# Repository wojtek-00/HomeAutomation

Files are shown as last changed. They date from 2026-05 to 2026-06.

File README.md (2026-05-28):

# HomeAutomation

A modular home automation system built around ESPHome, custom PCB design (KiCad), and 3D-printed enclosures.

The project is designed to be **scalable**, allowing multiple independent hardware modules (controller + expanders) that integrate into a single automation system.

---

# 🧠 System Overview

The project is split into two main domains:

## 🧩 hardware/
Contains all physical devices and their design artifacts:

- PCB designs (KiCad)
- 3D enclosures (STEP / CAD files)
- front panels / UI elements
- production-ready snapshots (releases)

Each hardware module is self-contained.

### Current modules:
- `system_controller` – main brain of the system
- `relay_expander` – relay output module (8 outputs + 8 inputs)
- *(future expanders will be added here)*

---

## ⚙️ system/
Contains software and logic:

- ESPHome configurations
- automation logic (e.g. Home Assistant)
- device behavior definitions
- shared system-level configuration

This layer defines **how devices behave**, not how they are built.

---

# 🏗️ Hardware Module Structure

Each hardware module follows the same structure:
 - hardware/<module_name>/
 - current/ # active development (WIP)
 - releases/ # frozen production versions

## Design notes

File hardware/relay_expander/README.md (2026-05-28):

# Sprinkler Expander Module

## Overview

The **Sprinkler Expander Module** is a modular extension board designed for an ESP32-based controller system used with ESPHome home automation projects.

It provides additional digital I/O capabilities as well as flexible power handling for relay-driven actuator systems.

---

## Features

- 8× relay outputs
- 8× digital inputs
- Modular design for sprinkler and automation systems
- Power distribution system with configurable relay supply
- Designed for integration with ESP32 System Controller

---

## Power Architecture

The module contains two independent power domains:

### 1. Logic Power (5V system supply)

- Onboard **bridge rectifier**
- Used to convert optional **AC input into DC**
- Followed by a **5V buck converter**
- Supplies power for:
  - Relay coils
  - ESP32 System Controller (optional power path)

> This allows the system to be powered either from AC or DC sources.

---

### 2. Relay Power Domain

Relay outputs are powered separately from the logic section.

- Default supply: **24VAC (or equivalent external supply)**
- Each relay bank can be powered from a shared rail

#### Individual relay isolation

Each relay channel can be electrically isolated from the main relay power rail by removing a **jumper**.

This allows:
- independent relay supply per channel
- mixed-voltage operation
- custom actuator voltage per output

---

## System Behavior

- Logic section is always powered via 5V rail
- Relay coils may be powered from:
  - shared 24VAC rail (default mode)
  - or independent external supply per channel (jumper removed)

---

## Application

Typical applications:

- Irrigation / sprinkler control systems
- Valve actuation systems
- Distributed relay automation
- Mixed-voltage industrial control logic

---

## Integration

Designed for use with:

- ESP32 System Controller (ESPHome firmware)
- Modular expansion architecture
- DIN rail mounted enclosures

---

## Notes

- Ensure correct jumper configuration before applying relay power
- Do not mix AC and DC relay supply on the same channel
- Verify coil voltage compatibility before deployment

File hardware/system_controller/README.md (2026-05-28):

# ESP32 Modular DIN Rail Controller for ESPHome

This repository contains PCB schematics and PCB design files for a modular ESP32-based controller designed for use with ESPHome.

The controller supports expansion modules that provide additional functionality such as extra GPIO, PWM outputs, relays, and other peripherals.

---

## Features

- ESP32-based controller
- Designed for ESPHome
- Modular expansion system
- DIN rail mount enclosure
- Easy integration with custom modules

---

## Supported Expansion Modules

Examples of supported modules:

- GPIO expanders
- PWM output modules
- Relay modules
- Analog input modules
- Custom extension boards

---

## Enclosure Parameters (Fusion 360)

| Parameter | Value |
|---|---|
| Enclosure type | `RailEnclosure_One_Side` |
| Board width | `45 mm` |

---

## Project Structure

```text
/pcb            -> PCB design files
/schematics     -> Electrical schematics
/fusion360      -> Enclosure and mechanical design
/docs           -> Documentation
```

---

## Software

The controller is designed to work with ESPHome firmware.

ESPHome allows easy integration with Home Assistant and other home automation systems.

More information:
https://esphome.io/

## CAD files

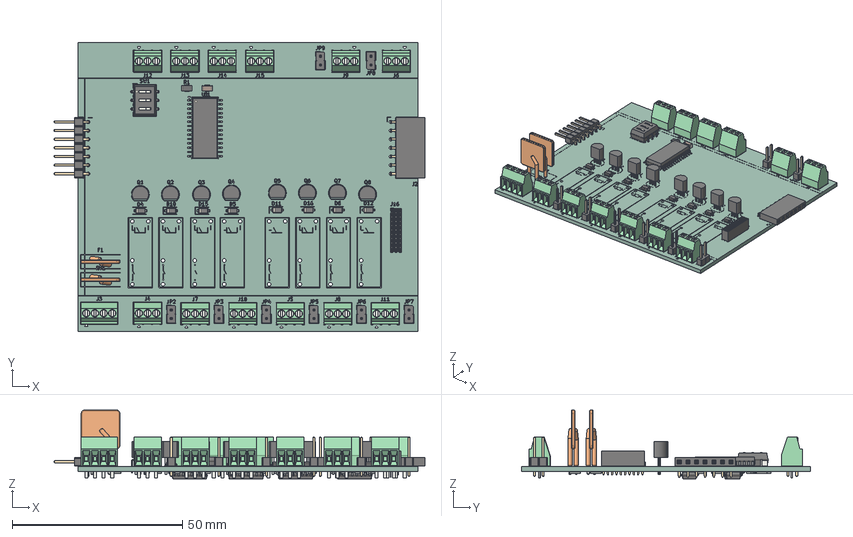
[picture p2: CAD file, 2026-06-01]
hardware/relay_expander/current/pcb/main_board/main_board.step
109.1 x 85.0 x 20.3 mm
R_1206_3216Metric x 44
TerminalBlock_Phoenix_MPT-0,5-4-2.54_1x04_P2.54mm_Horizontal
TerminalBlock_Phoenix_MPT-0,5-3-2.54_1x03_P2.54mm_Horizontal x 12
D_SOD-123 x 8
TO-92_Inline_Narrow x 8
PinHeader_1x02_P254mm_Vertical x 8
SW_DIP_SPSTx03_Slide_67x918mm_W762mm_P254mm_LowProfile
PinHeader_1x07_P254mm_Horizontal
C_1206_3216Metric
PinSocket_2x10_P1.27mm_Vertical
SOIC-28W_7.5x17.9mm_P1.27mm
PinSocket_1x07_P2.54mm_Horizontal
A_0ZRE0033FF x 2
SOP-16_4.4x10.4mm_P1.27mm x 4
main_board_silkscreen x 2
main_board_PCB

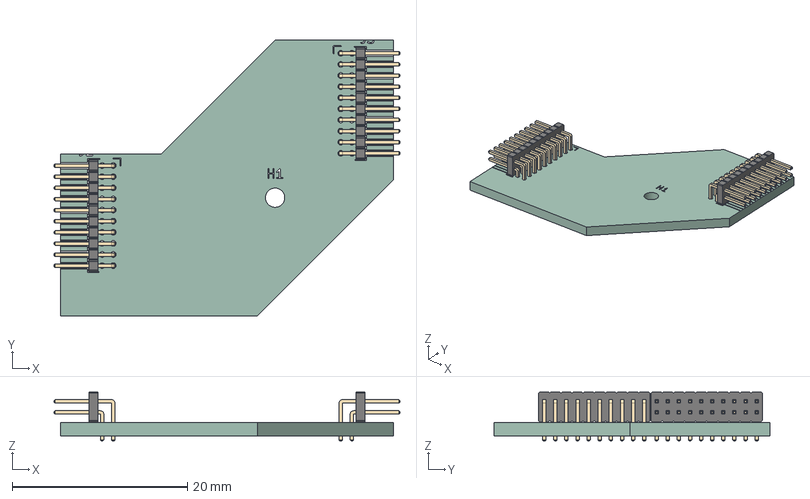
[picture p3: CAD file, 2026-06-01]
hardware/relay_expander/current/pcb/boards_connector/boards_connector.step
39.5 x 31.5 x 5.58 mm
PinHeader_2x10_P127mm_Horizontal x 2
boards_connector_silkscreen
boards_connector_PCB

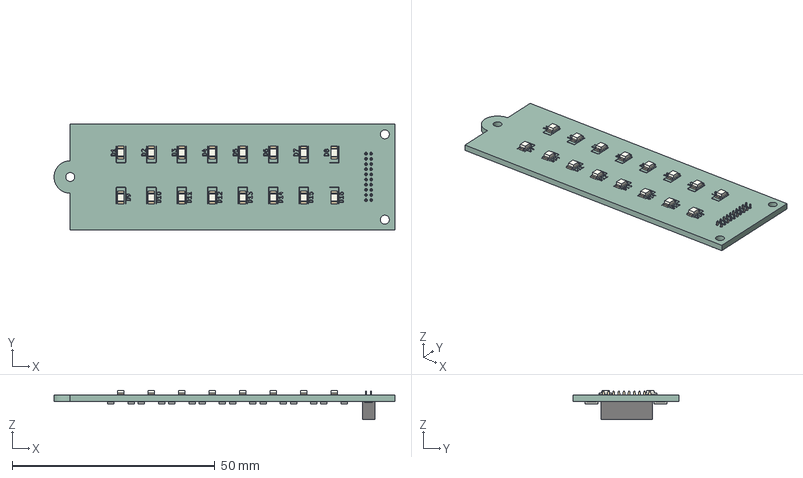
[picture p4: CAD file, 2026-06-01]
hardware/relay_expander/current/pcb/ui_board/ui_board.step
84.0 x 26.0 x 7.18 mm
LED_1206_3216Metric x 16
R_1206_3216Metric x 16
PinSocket_2x10_P1.27mm_Vertical
ui_board_silkscreen x 2
ui_board_PCB

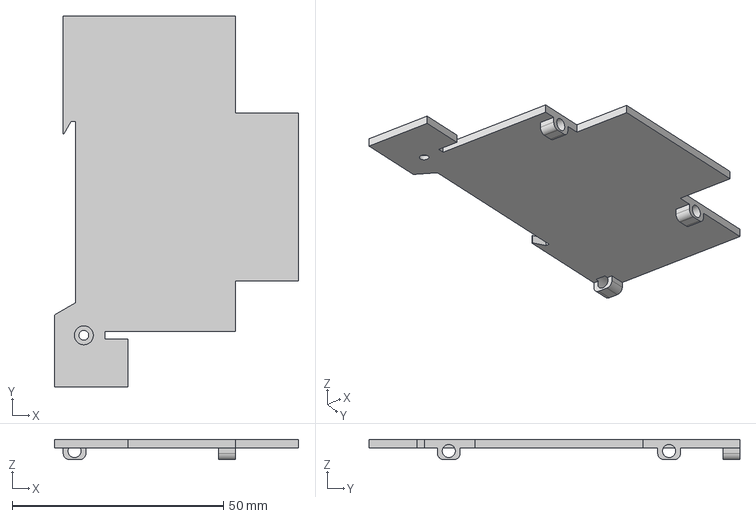
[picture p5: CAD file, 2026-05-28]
hardware/system_controller/current/enclosure/side_lid.step
57.9 x 87.9 x 4.80 mm

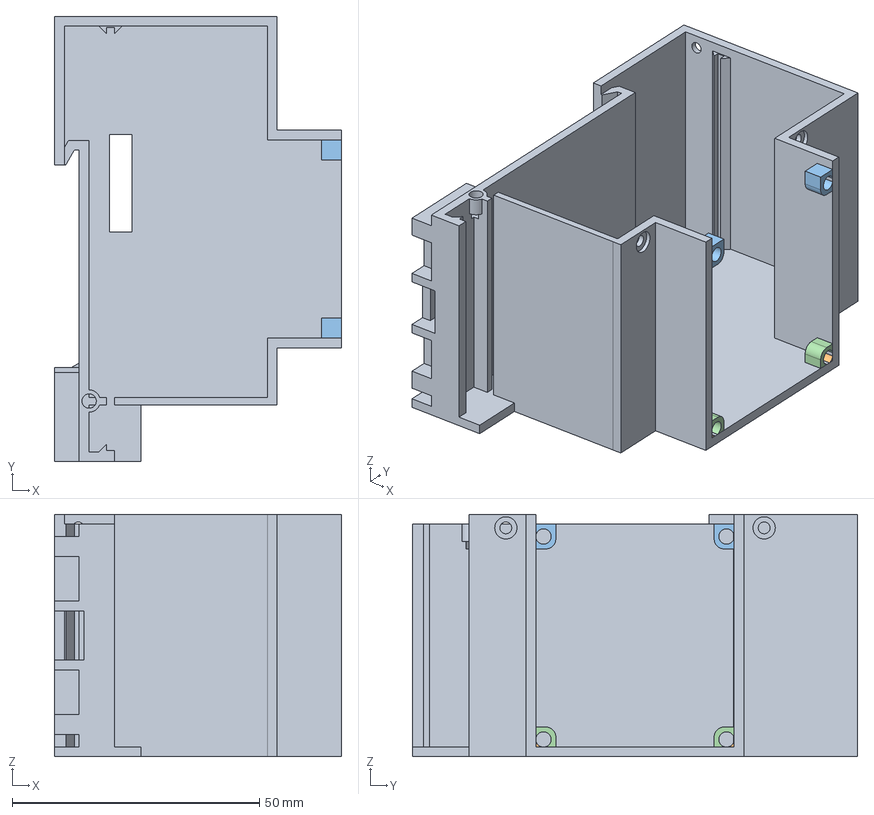
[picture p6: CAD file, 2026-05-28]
hardware/system_controller/current/enclosure/enclosure_base.step
58.0 x 90.0 x 49.0 mm

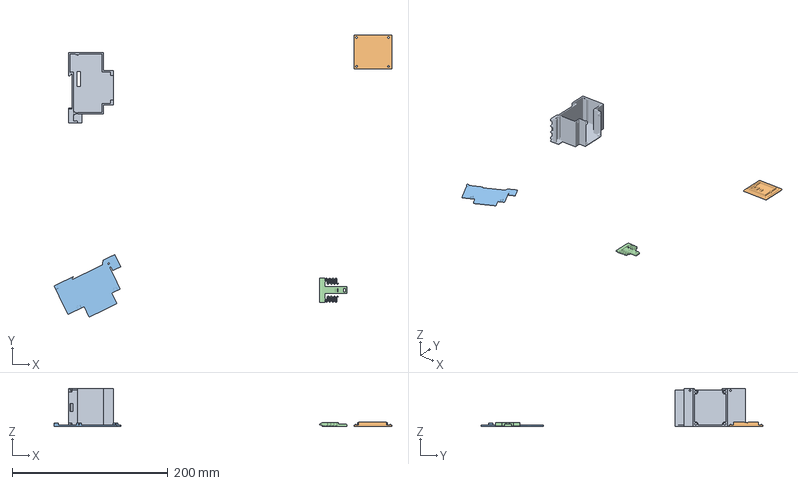
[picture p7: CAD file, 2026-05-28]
hardware/system_controller/releases/v1.0.0/enclosure/print_setup.3mf
433.9 x 362.5 x 49.0 mm
System_Controller_Enclosure.step
LED_Lid_System_Controller.step
Lid_One_Side.step
DIN_2Mod_Clip.STL

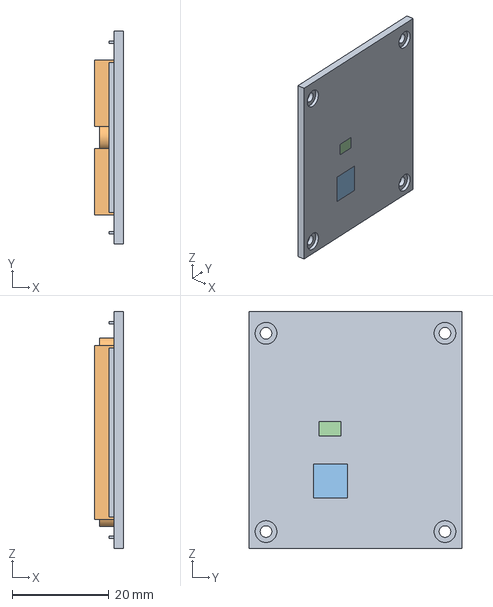
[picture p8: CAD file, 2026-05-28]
hardware/system_controller/current/enclosure/front_panel.step
6.00 x 44.0 x 49.0 mm

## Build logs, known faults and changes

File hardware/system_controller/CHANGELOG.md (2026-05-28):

# System Controller Changelog

## [v1.0.0] - 2026-05-27

### Hardware
- controller_board v1 (ESP32 + power section)
- ui_board v1 (LED + reset + buttons)
- enclosure v1 (3D printed housing)

### Notes
- first working full assembly
- UI LEDs confirmed working

### Release
- stored in hardware/system_controller/releases/v1.0.0

---

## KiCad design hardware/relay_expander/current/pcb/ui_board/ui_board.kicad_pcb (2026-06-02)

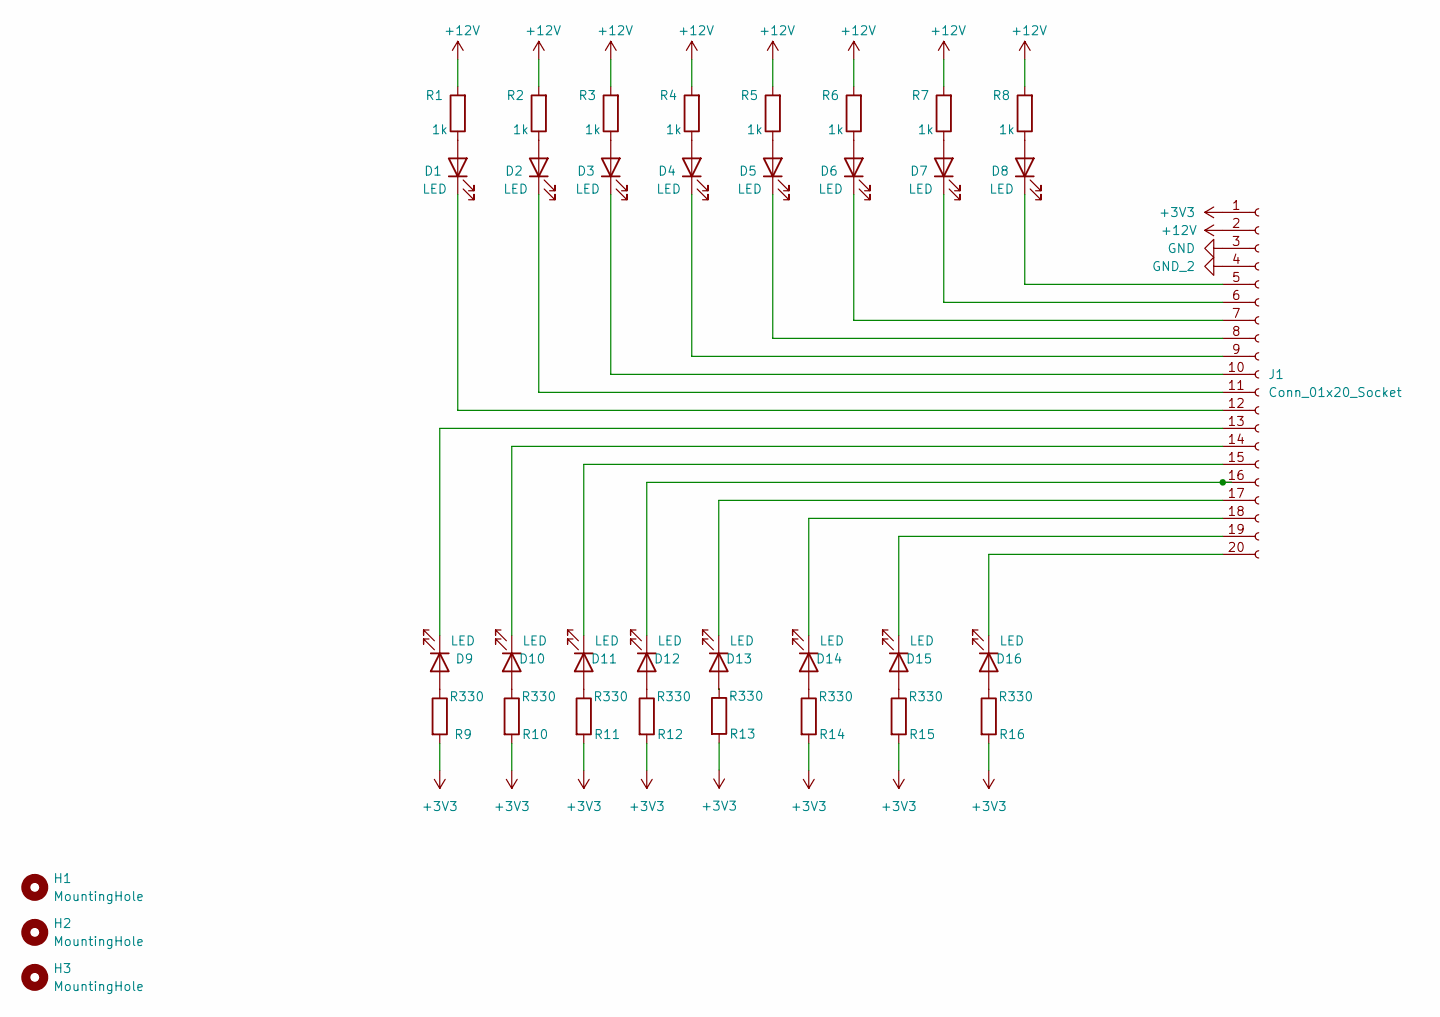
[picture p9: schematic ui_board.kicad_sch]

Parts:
D1, D2, D3, D4, D5, D6, D7, D8, D9, D10, D11, D12, D13, D14, D15, D16: LED; LED_1206_3216Metric_Pad1.42x1.75mm_HandSolder
H1, H2, H3: MountingHole; MountingHole_2.2mm_M2_ISO7380_Pad_TopOnly
J1: Conn_01x20_Socket; PinSocket_2x10_P1.27mm_Vertical
R1, R2, R3, R4, R5, R6, R7, R8: 1k; R_1206_3216Metric_Pad1.30x1.75mm_HandSolder
R9, R10, R11, R12, R13, R14, R15, R16: R330; R_1206_3216Metric_Pad1.30x1.75mm_HandSolder

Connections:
+3V3: J1.1, R9.2, R10.2, R11.2, R12.2, R13.2, R14.2, R15.2, R16.2
+12V: J1.2, R1.2, R2.2, R3.2, R4.2, R5.2, R6.2, R7.2, R8.2
GND: J1.3
GND_2: J1.4
unnamed: D1.2 (A), R1.1
unnamed: D1.1 (K), J1.12
unnamed: D2.2 (A), R2.1
unnamed: D2.1 (K), J1.11
unnamed: D3.2 (A), R3.1
unnamed: D3.1 (K), J1.10
unnamed: D4.2 (A), R4.1
unnamed: D4.1 (K), J1.9
unnamed: D5.2 (A), R5.1
unnamed: D5.1 (K), J1.8
unnamed: D6.2 (A), R6.1
unnamed: D6.1 (K), J1.7
unnamed: D7.2 (A), R7.1
unnamed: D7.1 (K), J1.6
unnamed: D8.2 (A), R8.1
unnamed: D8.1 (K), J1.5
unnamed: D9.2 (A), R9.1
unnamed: D9.1 (K), J1.13
unnamed: D10.2 (A), R10.1
unnamed: D10.1 (K), J1.14
unnamed: D11.2 (A), R11.1
unnamed: D11.1 (K), J1.15
unnamed: D12.2 (A), R12.1
unnamed: D12.1 (K), J1.16
unnamed: D13.2 (A), R13.1
unnamed: D13.1 (K), J1.17
unnamed: D14.2 (A), R14.1
unnamed: D14.1 (K), J1.18
unnamed: D15.2 (A), R15.1
unnamed: D15.1 (K), J1.19
unnamed: D16.2 (A), R16.1
unnamed: D16.1 (K), J1.20

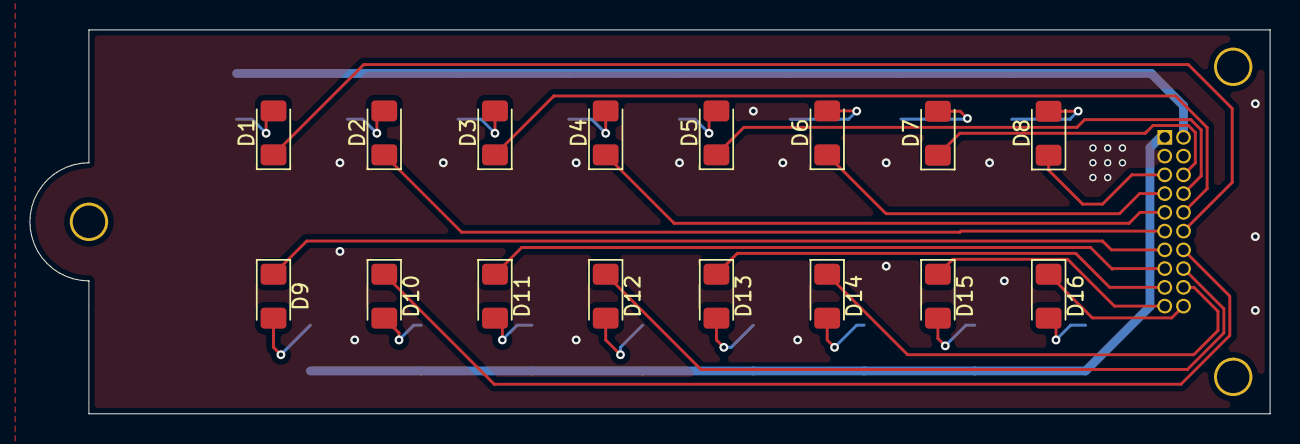
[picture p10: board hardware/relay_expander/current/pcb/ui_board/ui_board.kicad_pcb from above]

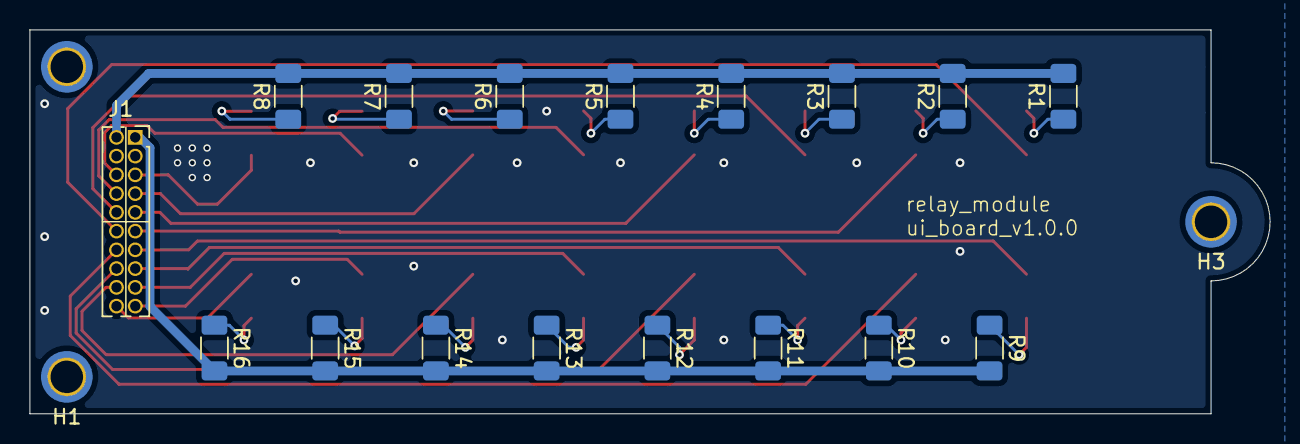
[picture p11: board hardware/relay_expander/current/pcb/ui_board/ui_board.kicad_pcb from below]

Board: 2 copper layers, 84.0 x 26.0 mm, 36 parts (20 on the bottom side), 34 nets.

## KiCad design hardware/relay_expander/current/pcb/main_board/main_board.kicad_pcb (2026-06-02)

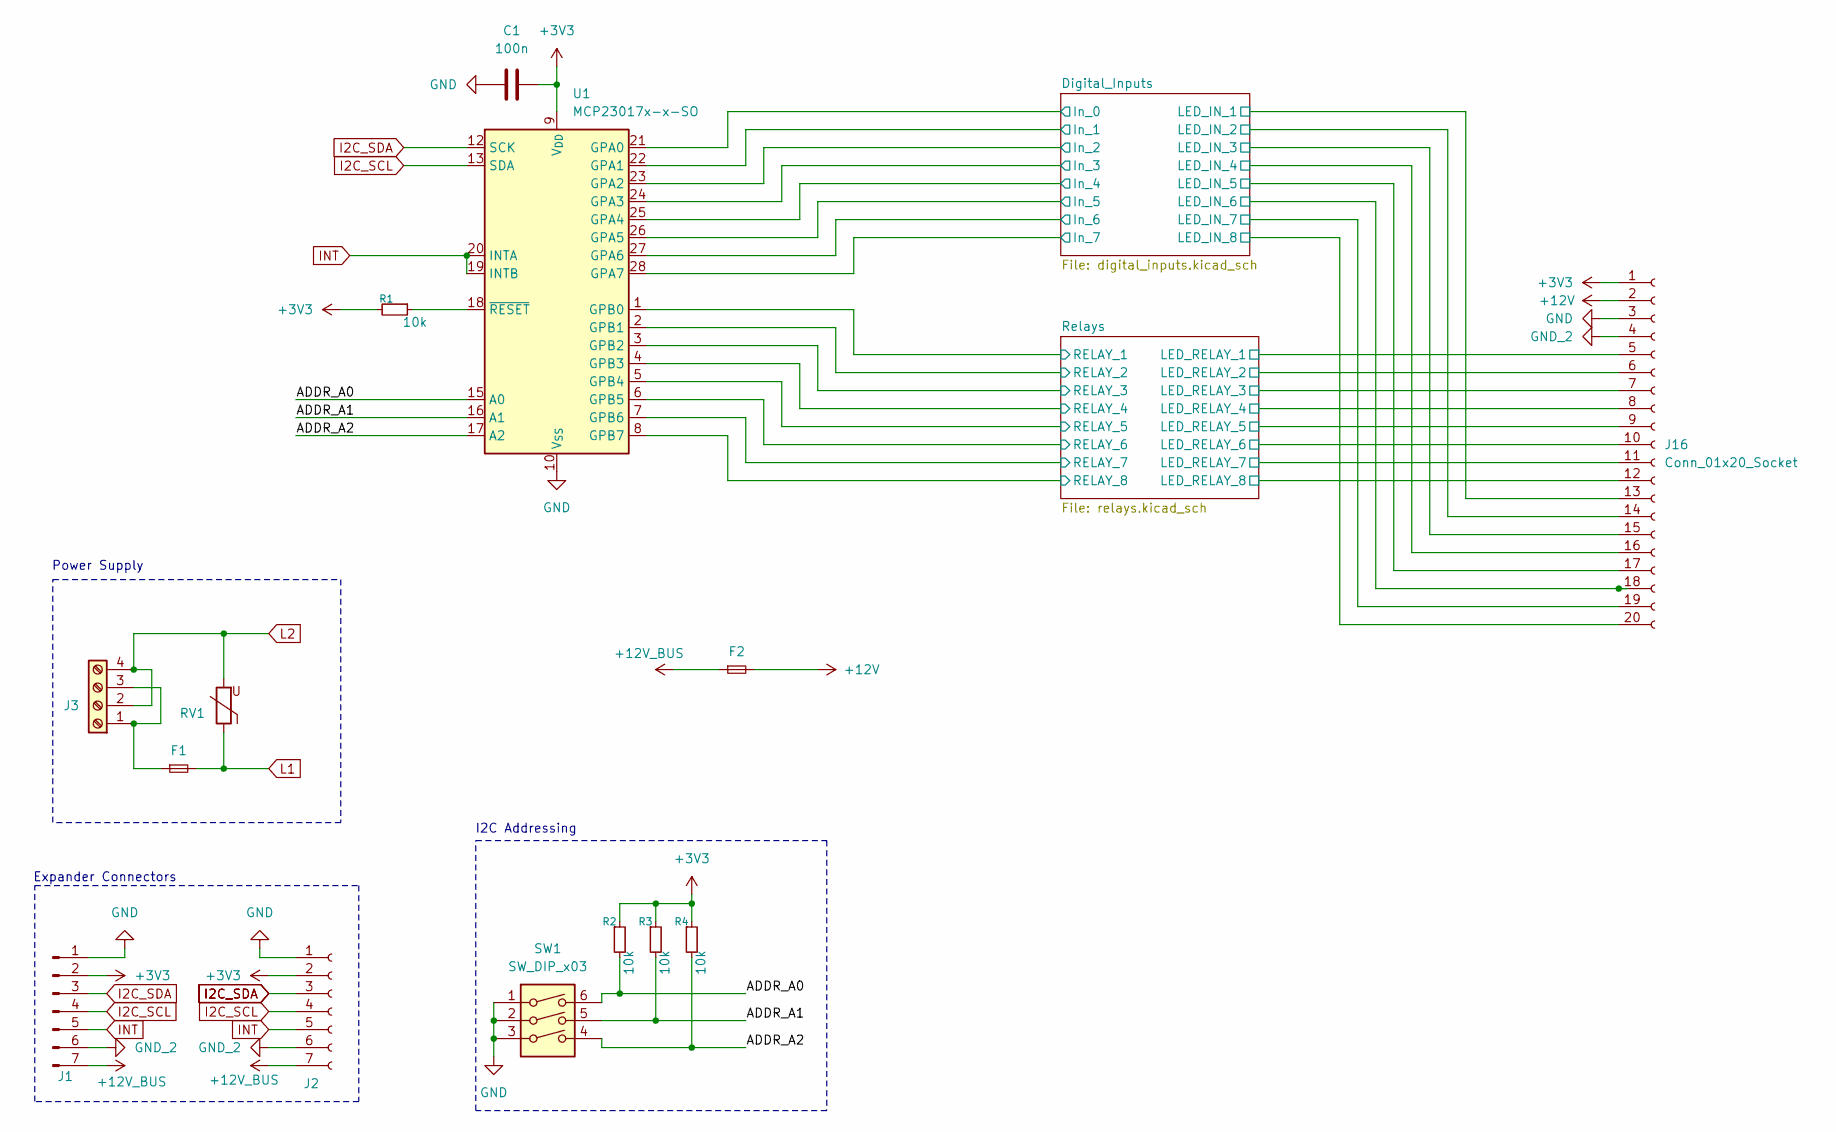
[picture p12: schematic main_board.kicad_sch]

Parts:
C1: 100n; C_1206_3216Metric_Pad1.33x1.80mm_HandSolder
F1: 1A, PTC; Fuse_BelFuse_0ZRE0033FF_L11.4mm_W3.8mm
F2: 0.5A; Fuse_1206_3216Metric
J1: Conn_01x07_Socket; PinHeader_1x07_P2.54mm_Horizontal_left
J2: Conn_01x07_Socket; PinSocket_1x07_P2.54mm_Horizontal_Right
J3: Screw_Terminal_01x04; TerminalBlock_Xinya_XY308-2.54-4P_1x04_P2.54mm_Horizontal
J16: Conn_01x20_Socket; PinSocket_2x10_P1.27mm_Vertical
R1, R2, R3, R4: 10k; R_1206_3216Metric_Pad1.30x1.75mm_HandSolder
RV1: 39V, 250A; Fuse_BelFuse_0ZRE0033FF_L11.4mm_W3.8mm
SW1: SW_DIP_x03; SW_DIP_SPSTx03_Slide_6.7x9.18mm_W7.62mm_P2.54mm_LowProfile
U1: MCP23017x-x-SO; SOIC-28W_7.5x17.9mm_P1.27mm

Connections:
+3V3: C1.2, J1.2, J2.2, J16.1, R1.2, R2.1, R3.1, R4.1, U1.9 (V_{DD}); also elsewhere on the board
+12V: F2.2, J16.2; also elsewhere on the board
+12V_BUS: F2.1, J1.7, J2.7
/ADDR_A0: R2.2, SW1.6, U1.15 (A0)
/ADDR_A1: R3.2, SW1.5, U1.16 (A1)
/ADDR_A2: R4.2, SW1.4, U1.17 (A2)
/Digital_Inputs/In_0: J16.13, U1.21 (GPA0); also elsewhere on the board
/Digital_Inputs/In_1: J16.14, U1.22 (GPA1); also elsewhere on the board
/Digital_Inputs/In_2: J16.15, U1.23 (GPA2); also elsewhere on the board
/Digital_Inputs/In_3: J16.16, U1.24 (GPA3); also elsewhere on the board
/Digital_Inputs/In_4: J16.17, U1.25 (GPA4); also elsewhere on the board
/Digital_Inputs/In_5: J16.18, U1.26 (GPA5); also elsewhere on the board
/Digital_Inputs/In_6: J16.19, U1.27 (GPA6); also elsewhere on the board
/Digital_Inputs/In_7: J16.20, U1.28 (GPA7); also elsewhere on the board
/Relays/LED_RELAY_1: J16.5; also elsewhere on the board
/Relays/LED_RELAY_2: J16.6; also elsewhere on the board
/Relays/LED_RELAY_3: J16.7; also elsewhere on the board
/Relays/LED_RELAY_4: J16.8; also elsewhere on the board
/Relays/LED_RELAY_5: J16.9; also elsewhere on the board
/Relays/LED_RELAY_6: J16.10; also elsewhere on the board
/Relays/LED_RELAY_7: J16.11; also elsewhere on the board
/Relays/LED_RELAY_8: J16.12; also elsewhere on the board
/Relays/RELAY_1: U1.1 (GPB0); also elsewhere on the board
/Relays/RELAY_2: U1.2 (GPB1); also elsewhere on the board
/Relays/RELAY_3: U1.3 (GPB2); also elsewhere on the board
/Relays/RELAY_4: U1.4 (GPB3); also elsewhere on the board
/Relays/RELAY_5: U1.5 (GPB4); also elsewhere on the board
/Relays/RELAY_6: U1.6 (GPB5); also elsewhere on the board
/Relays/RELAY_7: U1.7 (GPB6); also elsewhere on the board
/Relays/RELAY_8: U1.8 (GPB7); also elsewhere on the board
GND: C1.1, J1.1, J2.1, J16.3, SW1.1, SW1.2, SW1.3, U1.10 (V_{SS}); also elsewhere on the board
GND_2: J1.6, J2.6, J16.4; also elsewhere on the board
I2C_SCL: J1.4, J2.4, U1.13 (SDA)
I2C_SDA: J1.3, J2.3, U1.12 (SCK)
INT: J1.5, J2.5, U1.19 (INTB), U1.20 (INTA)
L1: F1.2, RV1.1; also elsewhere on the board
L2: J3.2, J3.4, RV1.2; also elsewhere on the board
unnamed: F1.1, J3.1, J3.3
unnamed: R1.1, U1.18 (~RESET)

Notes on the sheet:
Expander Connectors
I2C Addressing
Power Supply

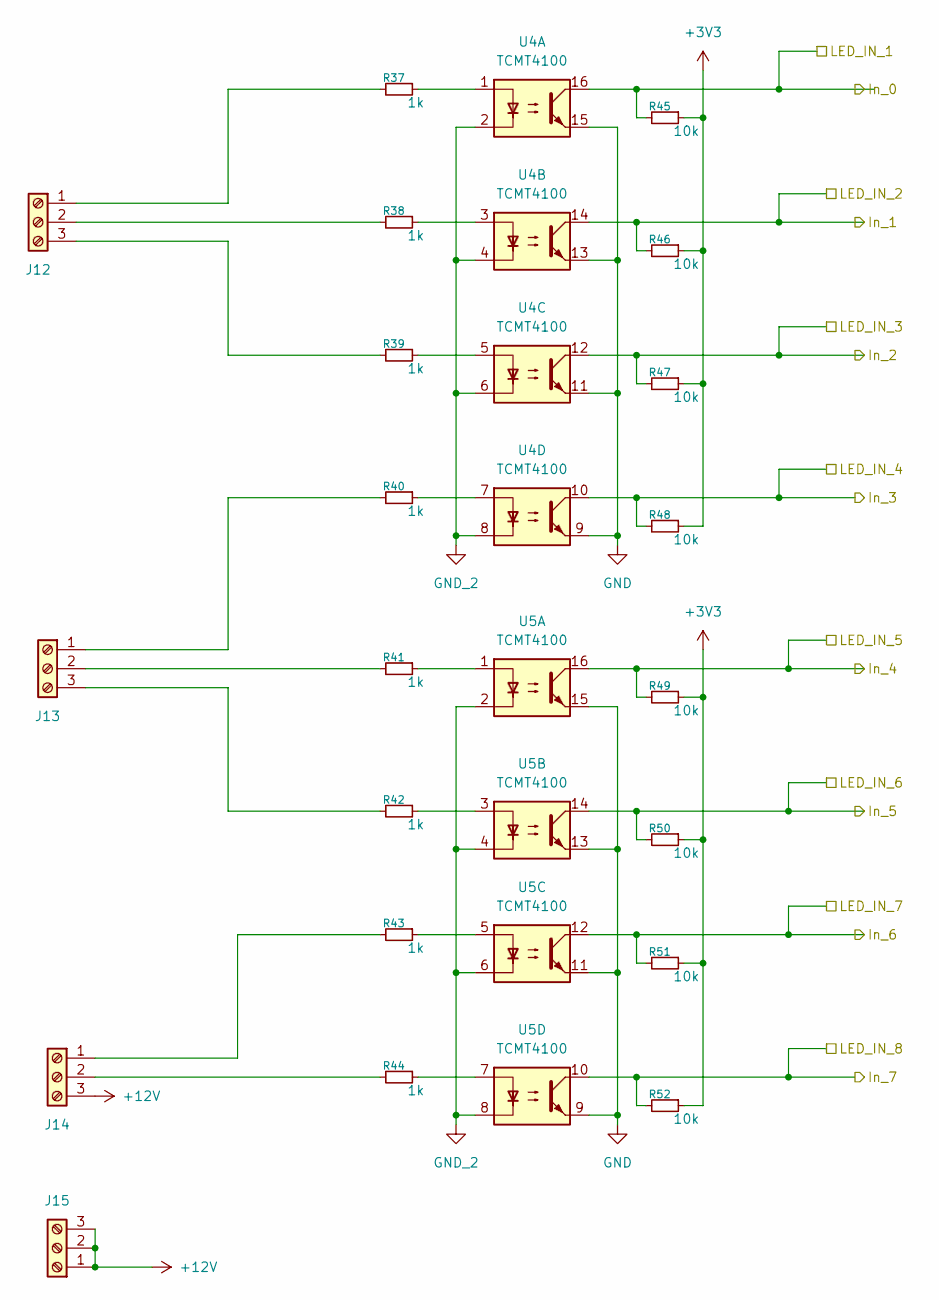
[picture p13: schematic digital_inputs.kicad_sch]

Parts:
J12, J13, J14, J15: Screw_Terminal_01x03; TerminalBlock_Phoenix_MPT-0,5-3-2.54_1x03_P2.54mm_Horizontal
R37, R38, R39, R40, R41, R42, R43, R44: 1k; R_1206_3216Metric_Pad1.30x1.75mm_HandSolder
R45, R46, R47, R48, R49, R50, R51, R52: 10k; R_1206_3216Metric_Pad1.30x1.75mm_HandSolder
U4, U5: TCMT4100; SOP-16_4.4x10.4mm_P1.27mm

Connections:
+3V3: R45.1, R46.1, R47.1, R48.1, R49.1, R50.1, R51.1, R52.1; also elsewhere on the board
+12V: J14.3, J15.1, J15.2, J15.3; also elsewhere on the board
/Digital_Inputs/In_0: R45.2, U4.16; also elsewhere on the board
/Digital_Inputs/In_1: R46.2, U4.14; also elsewhere on the board
/Digital_Inputs/In_2: R47.2, U4.12; also elsewhere on the board
/Digital_Inputs/In_3: R48.2, U4.10; also elsewhere on the board
/Digital_Inputs/In_4: R49.2, U5.16; also elsewhere on the board
/Digital_Inputs/In_5: R50.2, U5.14; also elsewhere on the board
/Digital_Inputs/In_6: R51.2, U5.12; also elsewhere on the board
/Digital_Inputs/In_7: R52.2, U5.10; also elsewhere on the board
GND: U4.9, U4.11, U4.13, U4.15, U5.9, U5.11, U5.13, U5.15; also elsewhere on the board
GND_2: U4.2, U4.4, U4.6, U4.8, U5.2, U5.4, U5.6, U5.8; also elsewhere on the board
unnamed: J12.1, R37.2
unnamed: J12.2, R38.2
unnamed: J12.3, R39.2
unnamed: J13.1, R40.2
unnamed: J13.2, R41.2
unnamed: J13.3, R42.2
unnamed: J14.1, R43.2
unnamed: J14.2, R44.2
unnamed: R37.1, U4.1
unnamed: R38.1, U4.3
unnamed: R39.1, U4.5
unnamed: R40.1, U4.7
unnamed: R41.1, U5.1
unnamed: R42.1, U5.3
unnamed: R43.1, U5.5
unnamed: R44.1, U5.7

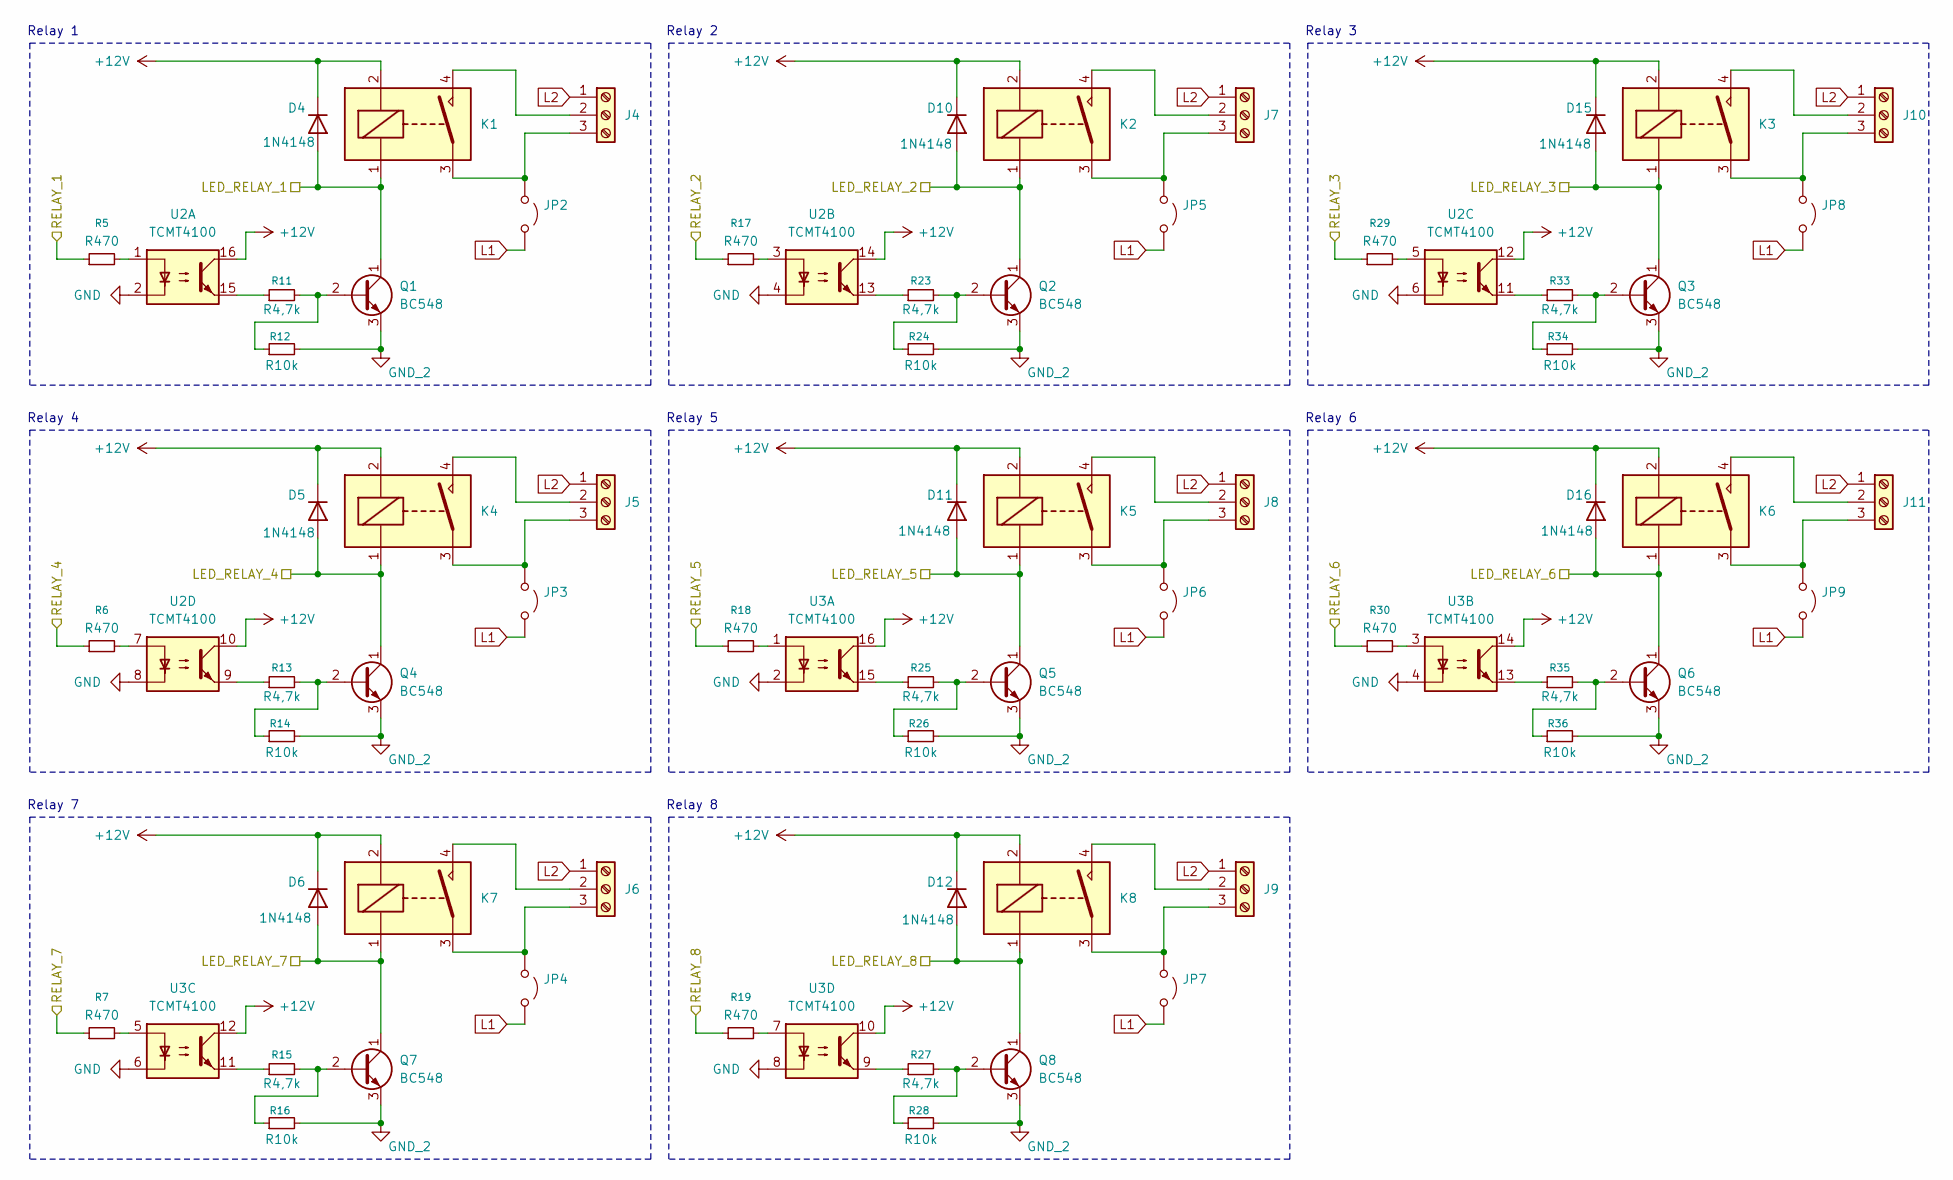
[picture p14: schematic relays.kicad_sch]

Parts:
D4, D5, D6, D10, D11, D12, D15, D16: 1N4148; D_SOD-123
J4, J5, J6, J7, J8, J9, J10, J11: Screw_Terminal_01x03; TerminalBlock_Phoenix_MPT-0,5-3-2.54_1x03_P2.54mm_Horizonta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
JP2, JP3, JP4, JP5, JP6, JP7, JP8, JP9: Jumper_2_Open; PinHeader_1x02_P2.54mm_Vertical
K1, K2, K3, K4, K5, K6, K7, K8: HF46F-12-HS1; relay_HF46F
Q1, Q2, Q3, Q4, Q5, Q6, Q7, Q8: BC548; TO-92_Inline
R5, R6, R7, R17, R18, R19, R29, R30: R470; R_1206_3216Metric_Pad1.30x1.75mm_HandSolder
R11, R13, R15, R23, R25, R27, R33, R35: R4,7k; R_1206_3216Metric_Pad1.30x1.75mm_HandSolder
R12, R14, R16, R24, R26, R28, R34, R36: R10k; R_1206_3216Metric_Pad1.30x1.75mm_HandSolder
U2, U3: TCMT4100; SOP-16_4.4x10.4mm_P1.27mm

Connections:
+12V: D4.1 (K), D5.1 (K), D6.1 (K), D10.1 (K), D11.1 (K), D12.1 (K), D15.1 (K), D16.1 (K), K1.2, K2.2, K3.2, K4.2, K5.2, K6.2, K7.2, K8.2, U2.10, U2.12, U2.14, U2.16, U3.10, U3.12, U3.14, U3.16; also elsewhere on the board
/Relays/LED_RELAY_1: D4.2 (A), K1.1, Q1.1 (C); also elsewhere on the board
/Relays/LED_RELAY_2: D10.2 (A), K2.1, Q2.1 (C); also elsewhere on the board
/Relays/LED_RELAY_3: D15.2 (A), K3.1, Q3.1 (C); also elsewhere on the board
/Relays/LED_RELAY_4: D5.2 (A), K4.1, Q4.1 (C); also elsewhere on the board
/Relays/LED_RELAY_5: D11.2 (A), K5.1, Q5.1 (C); also elsewhere on the board
/Relays/LED_RELAY_6: D16.2 (A), K6.1, Q6.1 (C); also elsewhere on the board
/Relays/LED_RELAY_7: D6.2 (A), K7.1, Q7.1 (C); also elsewhere on the board
/Relays/LED_RELAY_8: D12.2 (A), K8.1, Q8.1 (C); also elsewhere on the board
/Relays/RELAY_1: R5.1; also elsewhere on the board
/Relays/RELAY_2: R17.1; also elsewhere on the board
/Relays/RELAY_3: R29.1; also elsewhere on the board
/Relays/RELAY_4: R6.1; also elsewhere on the board
/Relays/RELAY_5: R18.1; also elsewhere on the board
/Relays/RELAY_6: R30.1; also elsewhere on the board
/Relays/RELAY_7: R7.1; also elsewhere on the board
/Relays/RELAY_8: R19.1; also elsewhere on the board
GND: U2.2, U2.4, U2.6, U2.8, U3.2, U3.4, U3.6, U3.8; also elsewhere on the board
GND_2: Q1.3 (E), Q2.3 (E), Q3.3 (E), Q4.3 (E), Q5.3 (E), Q6.3 (E), Q7.3 (E), Q8.3 (E), R12.2, R14.2, R16.2, R24.2, R26.2, R28.2, R34.2, R36.2; also elsewhere on the board
L1: JP2.2 (B), JP3.2 (B), JP4.2 (B), JP5.2 (B), JP6.2 (B), JP7.2 (B), JP8.2 (B), JP9.2 (B); also elsewhere on the board
L2: J4.1, J5.1, J6.1, J7.1, J8.1, J9.1, J10.1, J11.1; also elsewhere on the board
unnamed: J4.2, K1.4
unnamed: J4.3, JP2.1 (A), K1.3
unnamed: J5.2, K4.4
unnamed: J5.3, JP3.1 (A), K4.3
unnamed: J6.2, K7.4
unnamed: J6.3, JP4.1 (A), K7.3
unnamed: J7.2, K2.4
unnamed: J7.3, JP5.1 (A), K2.3
unnamed: J8.2, K5.4
unnamed: J8.3, JP6.1 (A), K5.3
unnamed: J9.2, K8.4
unnamed: J9.3, JP7.1 (A), K8.3
unnamed: J10.2, K3.4
unnamed: J10.3, JP8.1 (A), K3.3
unnamed: J11.2, K6.4
unnamed: J11.3, JP9.1 (A), K6.3
unnamed: Q1.2 (B), R11.2, R12.1
unnamed: Q2.2 (B), R23.2, R24.1
unnamed: Q3.2 (B), R33.2, R34.1
unnamed: Q4.2 (B), R13.2, R14.1
unnamed: Q5.2 (B), R25.2, R26.1
unnamed: Q6.2 (B), R35.2, R36.1
unnamed: Q7.2 (B), R15.2, R16.1
unnamed: Q8.2 (B), R27.2, R28.1
unnamed: R5.2, U2.1
unnamed: R6.2, U2.7
unnamed: R7.2, U3.5
unnamed: R11.1, U2.15
unnamed: R13.1, U2.9
unnamed: R15.1, U3.11
unnamed: R17.2, U2.3
unnamed: R18.2, U3.1
unnamed: R19.2, U3.7
unnamed: R23.1, U2.13
unnamed: R25.1, U3.15
unnamed: R27.1, U3.9
unnamed: R29.2, U2.5
unnamed: R30.2, U3.3
unnamed: R33.1, U2.11
unnamed: R35.1, U3.13

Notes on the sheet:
Relay 3
Relay 8
Relay 2
Relay 7
Relay 6
Relay 5
Relay 4
Relay 1

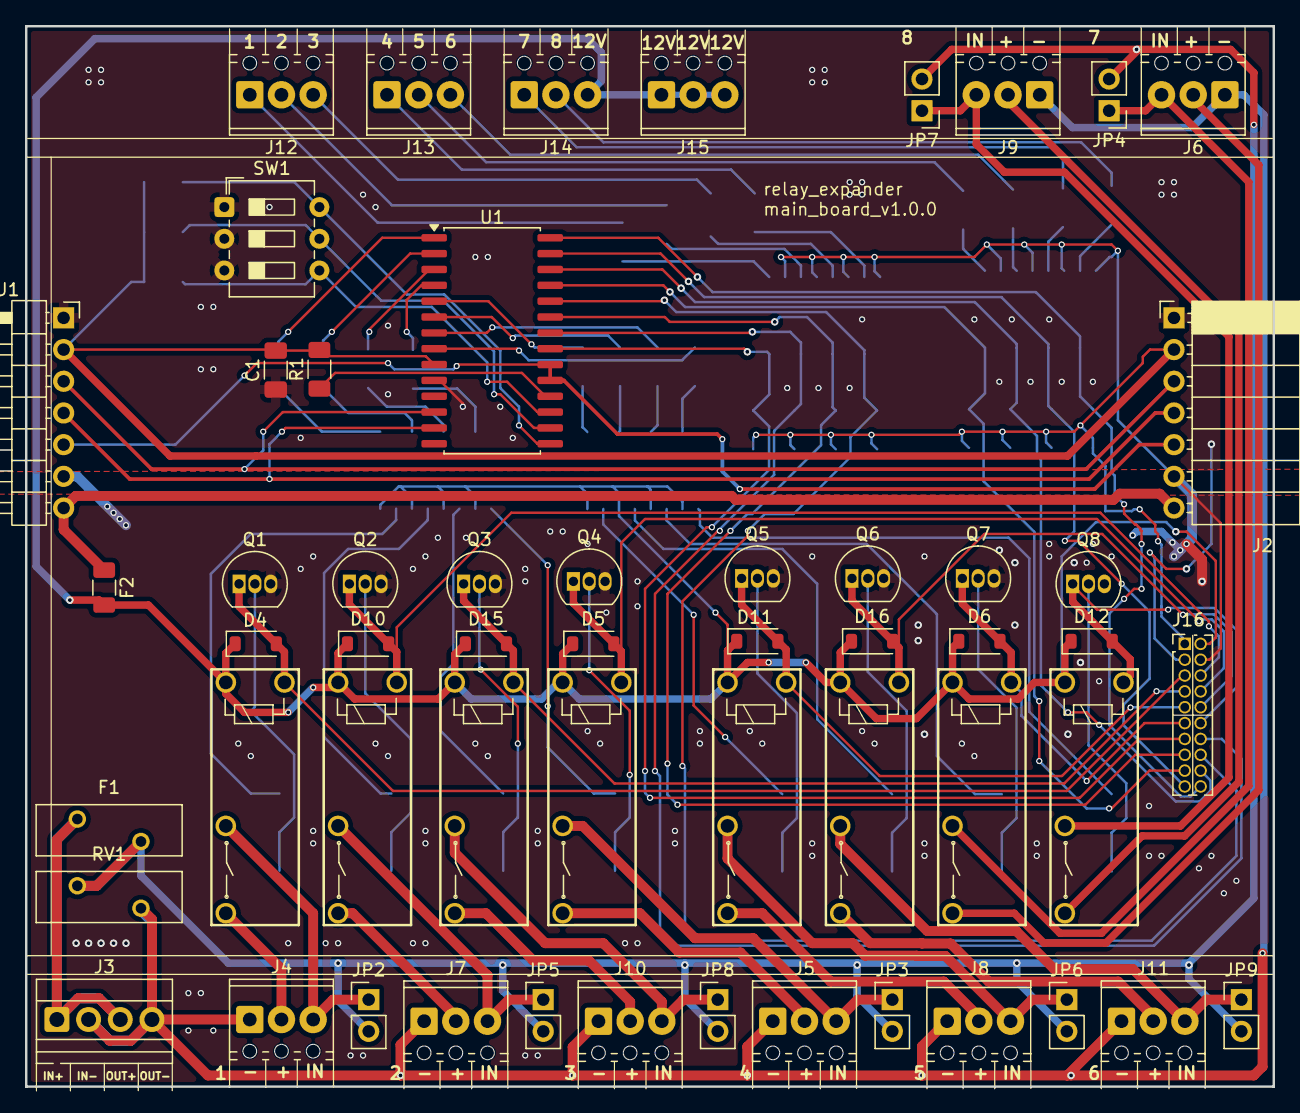
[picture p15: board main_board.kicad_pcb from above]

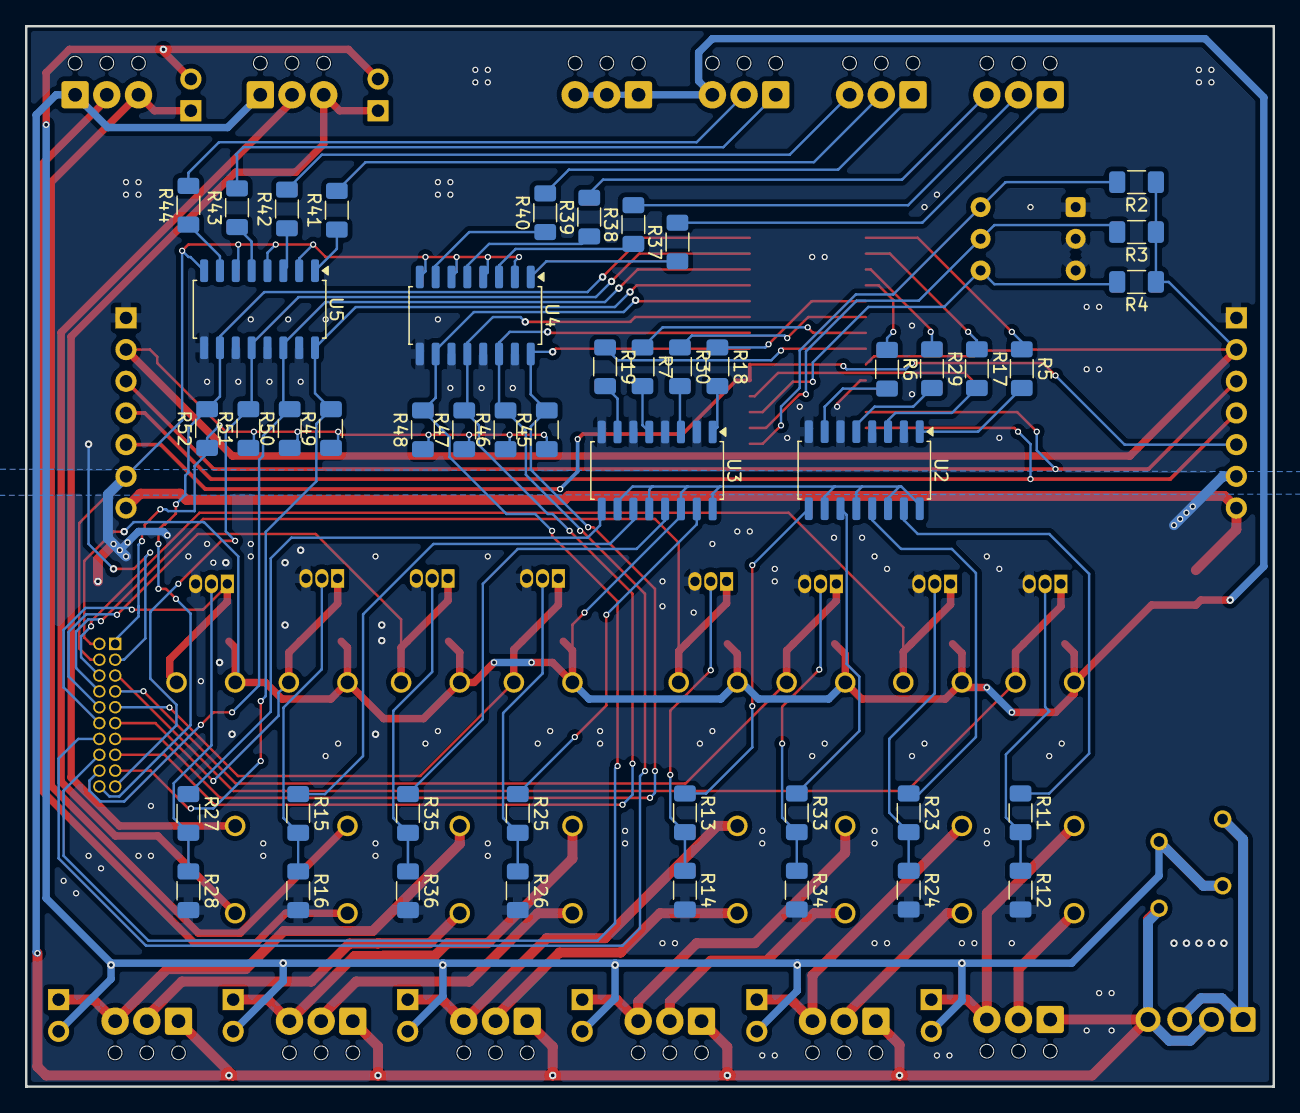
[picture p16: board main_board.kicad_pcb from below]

Board: 2 copper layers, 100.0 x 85.0 mm, 102 parts (47 on the bottom side), 95 nets.

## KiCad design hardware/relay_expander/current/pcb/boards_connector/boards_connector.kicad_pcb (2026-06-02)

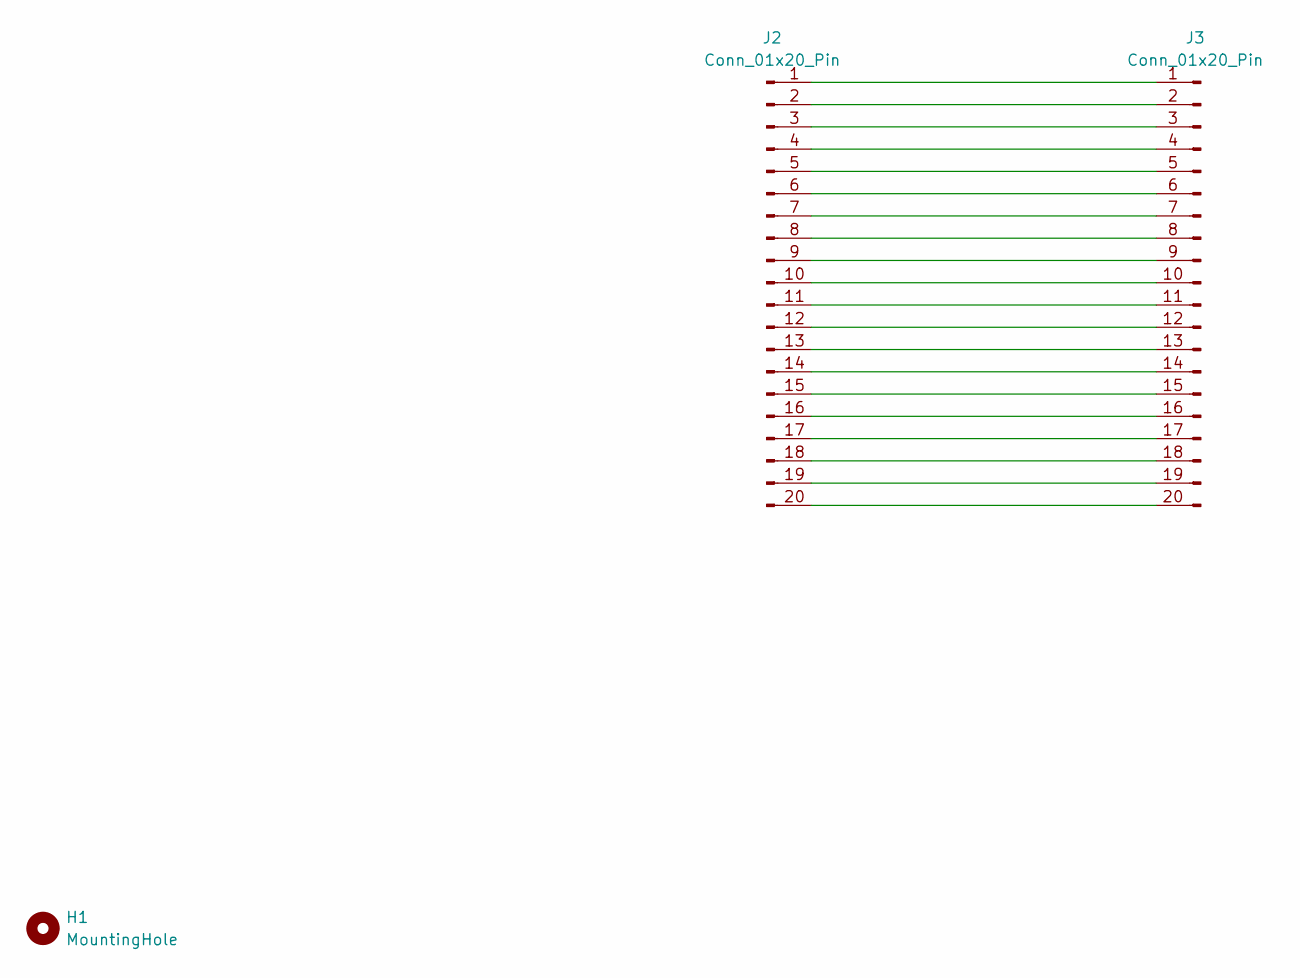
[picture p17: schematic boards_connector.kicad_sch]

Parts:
H1: MountingHole; MountingHole_2.2mm_M2_ISO7380_Pad_TopOnly
J2, J3: Conn_01x20_Pin; PinHeader_2x10_P1.27mm_Horizontal

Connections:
unnamed: J2.1, J3.1
unnamed: J2.2, J3.2
unnamed: J2.3, J3.3
unnamed: J2.4, J3.4
unnamed: J2.5, J3.5
unnamed: J2.6, J3.6
unnamed: J2.7, J3.7
unnamed: J2.8, J3.8
unnamed: J2.9, J3.9
unnamed: J2.10, J3.10
unnamed: J2.11, J3.11
unnamed: J2.12, J3.12
unnamed: J2.13, J3.13
unnamed: J2.14, J3.14
unnamed: J2.15, J3.15
unnamed: J2.16, J3.16
unnamed: J2.17, J3.17
unnamed: J2.18, J3.18
unnamed: J2.19, J3.19
unnamed: J2.20, J3.20

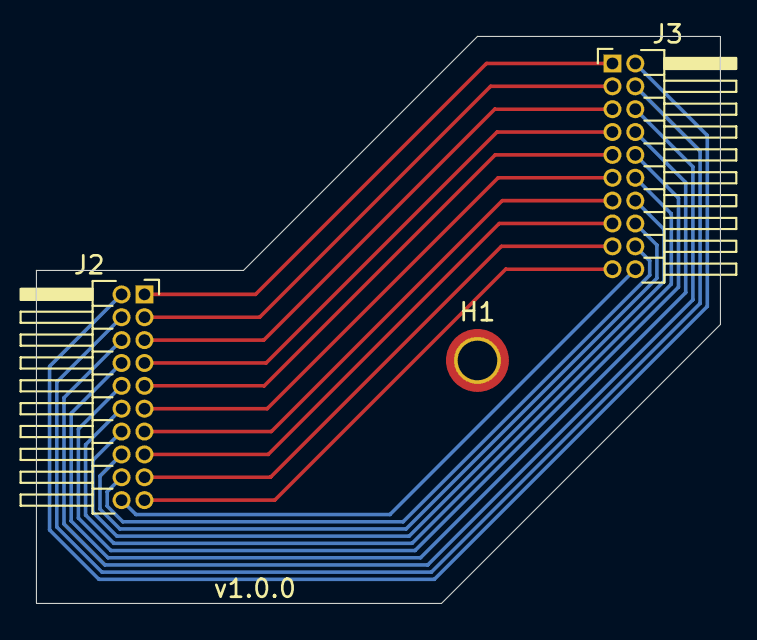
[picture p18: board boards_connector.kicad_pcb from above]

Board: 2 copper layers, 38.0 x 31.5 mm, 3 parts (0 on the bottom side), 20 nets.

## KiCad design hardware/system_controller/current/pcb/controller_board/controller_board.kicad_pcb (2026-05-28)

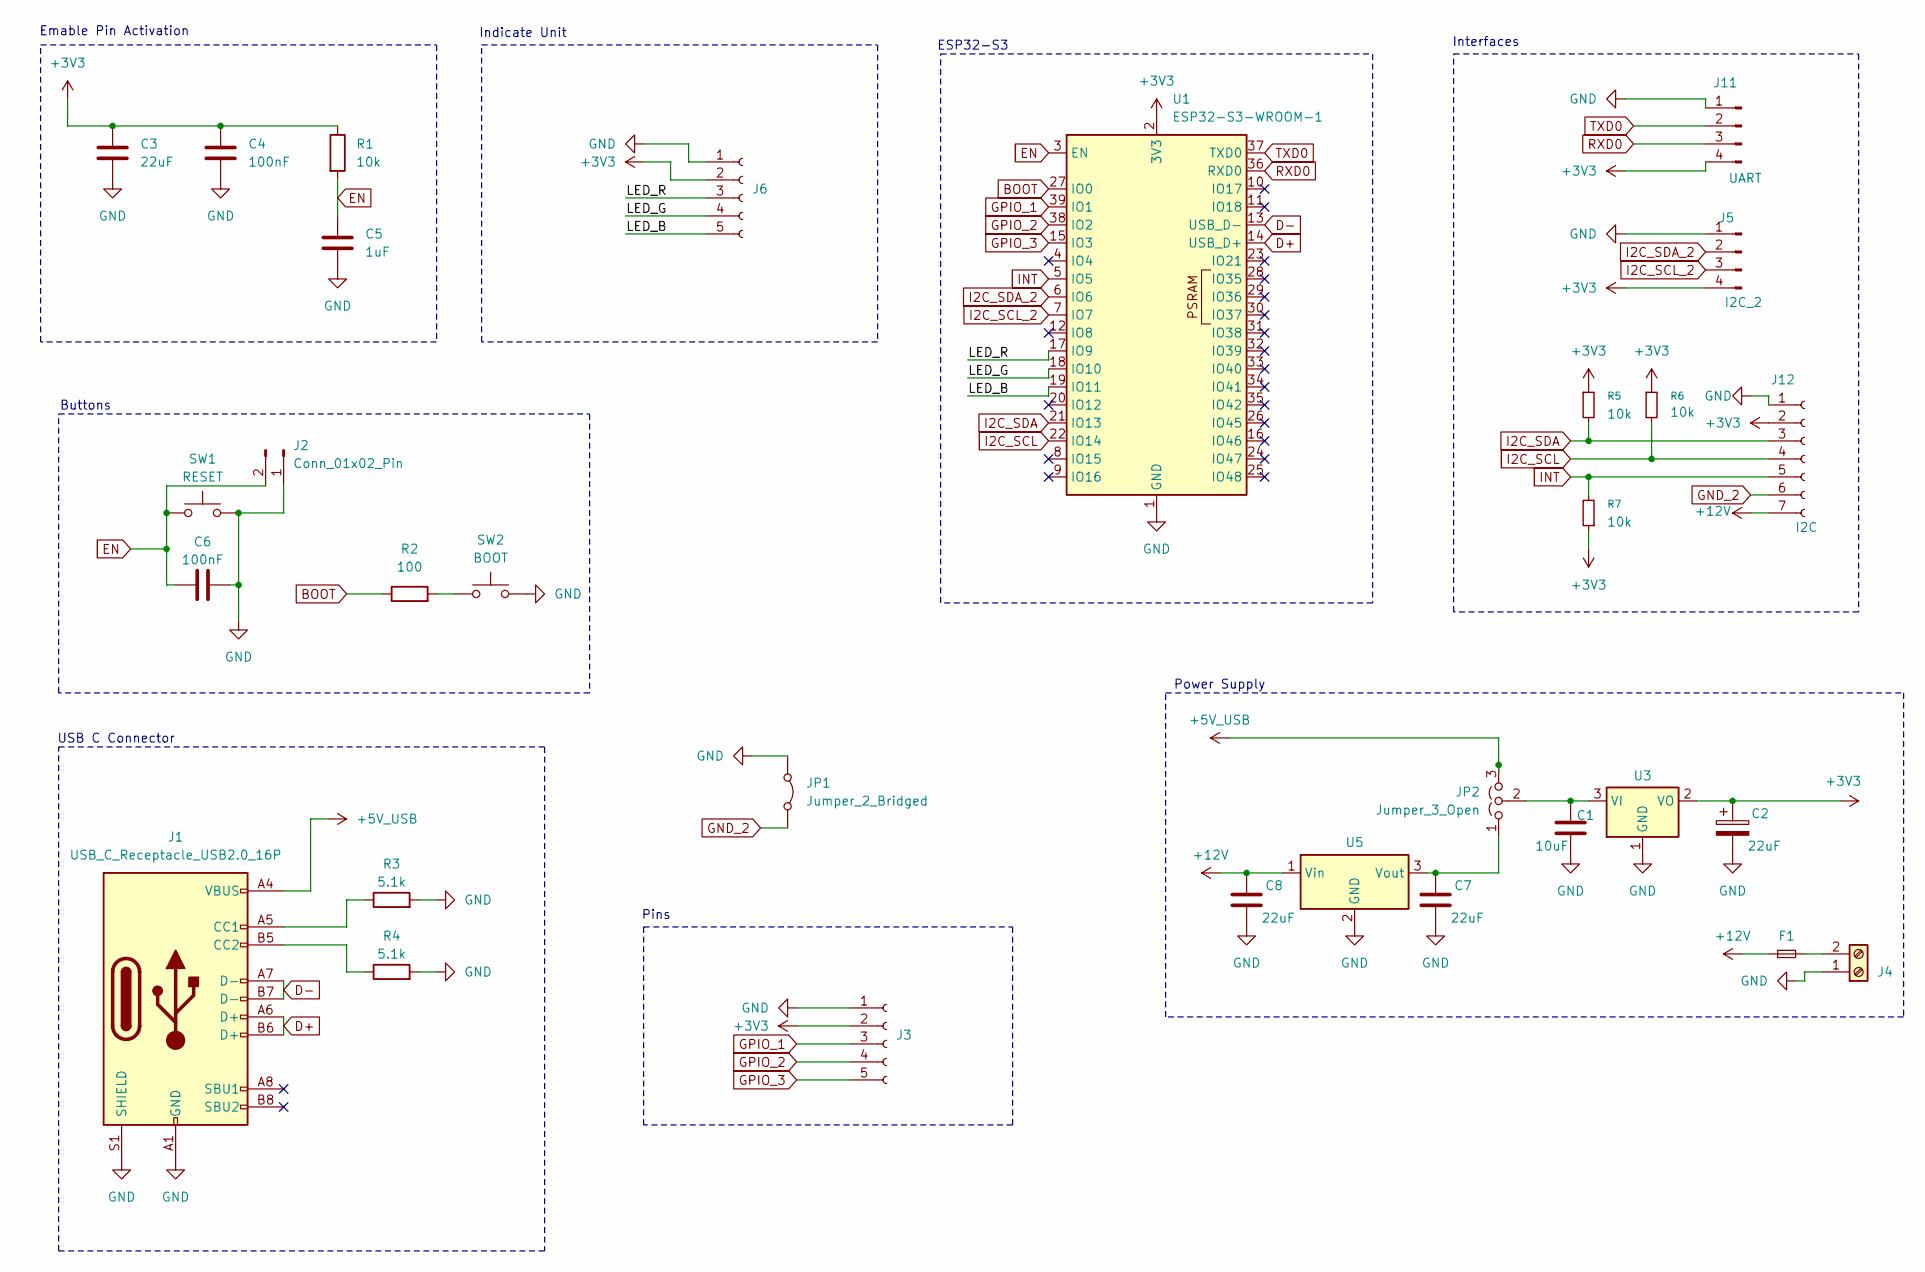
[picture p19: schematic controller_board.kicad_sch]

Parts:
C1: 10uF; C_1206_3216Metric_Pad1.33x1.80mm_HandSolder
C2: 22uF; CP_EIA-6032-15_Kemet-U
C3, C7, C8: 22uF; C_1206_3216Metric_Pad1.33x1.80mm_HandSolder
C4, C6: 100nF; C_1206_3216Metric_Pad1.33x1.80mm_HandSolder
C5: 1uF; C_1206_3216Metric_Pad1.33x1.80mm_HandSolder
F1: 1,1A, PTC; Fuse_BelFuse_0ZRE0033FF_L11.4mm_W3.8mm
J1: USB_C_Receptacle_USB2.0_16P; USB_C_Receptacle_GCT_USB4105-xx-A_16P_TopMnt_Horizontal
J2: Conn_01x02_Pin; PinHeader_1x02_P2.54mm_Vertical
J3: Conn_01x05_Socket; PinSocket_1x05_P2.54mm_Vertical
J4: Screw_Terminal_01x02; TerminalBlock_Phoenix_MPT-0,5-2-2.54_1x02_P2.54mm_Horizontal
J5: Conn_01x04_Pin; JST_PH_B4B-PH-K_1x04_P2.00mm_Vertical
J6: Conn_01x05_Socket; JST_PH_B5B-PH-K_1x05_P2.00mm_Vertical
J11: Conn_01x04_Pin; PinHeader_1x04_P2.54mm_Vertical
J12: Conn_01x07_Pin; PinSocket_1x07_P2.54mm_Horizontal_Right
JP1: Jumper_2_Bridged; PinHeader_1x02_P2.54mm_Vertical
JP2: Jumper_3_Open; PinHeader_1x03_P2.54mm_Vertical
R1, R5, R6, R7: 10k; R_1206_3216Metric_Pad1.30x1.75mm_HandSolder
R2: 100; R_1206_3216Metric_Pad1.30x1.75mm_HandSolder
R3, R4: 5.1k; R_1206_3216Metric_Pad1.30x1.75mm_HandSolder
SW1: RESET; SW_Push_SPST_NO_Alps_SKRK
SW2: BOOT; SW_Push_SPST_NO_Alps_SKRK
U1: ESP32-S3-WROOM-1
U3: AMS1117-3.3; SOT-223-3_TabPin2
U5: TSR1-2450E; Converter_DCDC_TRACO_TSR1-xxxxE_THT

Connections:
+3V3: C2.1, C3.1, C4.1, J3.2, J5.4, J6.2, J11.4, J12.2, R1.1, R5.1, R6.1, R7.1, U1.2 (3V3), U3.2 (VO)
+5V_USB: J1.A4 (VBUS), J1.A9 (VBUS), J1.B4 (VBUS), J1.B9 (VBUS), JP2.3 (B)
+12V: C8.1, F1.1, J12.7, U5.1 (Vin)
/LED_B: J6.5, U1.19 (IO11)
/LED_G: J6.4, U1.18 (IO10)
/LED_R: J6.3, U1.17 (IO9)
BOOT: R2.1, U1.27 (IO0)
D+: J1.A6 (D+), J1.B6 (D+), U1.14 (USB_D+)
D-: J1.A7 (D-), J1.B7 (D-), U1.13 (USB_D-)
EN: C5.1, C6.1, J2.2, R1.2, SW1.2, U1.3 (EN)
GND: C1.2, C2.2, C3.2, C4.2, C5.2, C6.2, C7.2, C8.2, J1.A1 (GND), J1.A12 (GND), J1.B1 (GND), J1.B12 (GND), J1.S1 (SHIELD), J2.1, J3.1, J4.1, J5.1, J6.1, J11.1, J12.1, JP1.1 (A), R3.2, R4.2, SW1.1, SW2.2, U1.1 (GND), U1.40 (GND), U1.41 (GND), U3.1 (GND), U5.2 (GND)
GND_2: J12.6, JP1.2 (B)
GPIO_1: J3.3, U1.39 (IO1)
GPIO_2: J3.4, U1.38 (IO2)
GPIO_3: J3.5, U1.15 (IO3)
I2C_SCL: J12.4, R6.2, U1.22 (IO14)
I2C_SCL_2: J5.3, U1.7 (IO7)
I2C_SDA: J12.3, R5.2, U1.21 (IO13)
I2C_SDA_2: J5.2, U1.6 (IO6)
INT: J12.5, R7.2, U1.5 (IO5)
unnamed: J1.A5 (CC1), R3.1
unnamed: J1.B5 (CC2), R4.1
unnamed: F1.2, J4.2
unnamed: C7.1, JP2.1 (A), U5.3 (Vout)
unnamed: C1.1, JP2.2 (C), U3.3 (VI)
unnamed: R2.2, SW2.1
RXD0: J11.3, U1.36 (RXD0)
TXD0: J11.2, U1.37 (TXD0)

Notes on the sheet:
Pins
USB C Connector
ESP32-S3
Power Supply
Indicate Unit
Buttons
Interfaces
Emable Pin Activation

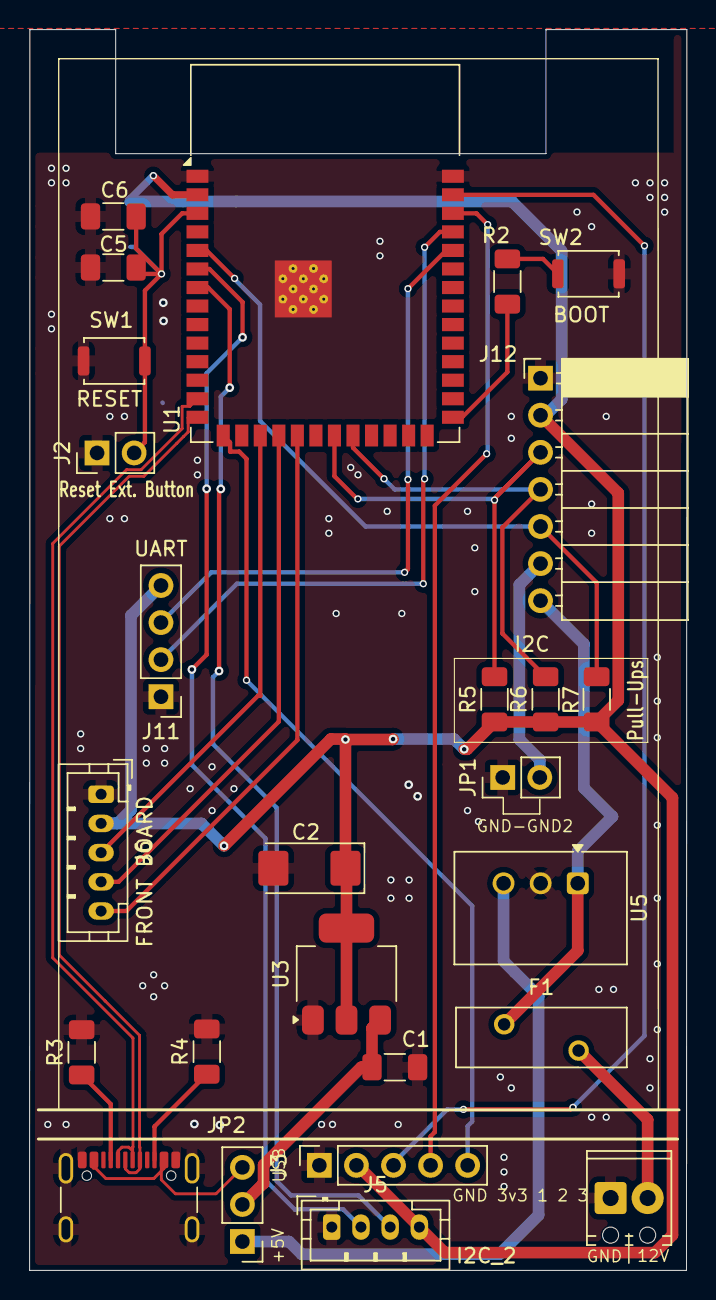
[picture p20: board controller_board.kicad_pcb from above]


Board: 2 copper layers, 45.0 x 85.0 mm, 31 parts (5 on the bottom side), 28 nets.

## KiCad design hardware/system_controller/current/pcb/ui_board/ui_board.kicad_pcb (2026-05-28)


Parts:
D1: LED_SMD_5050; LED_WS2812_PLCC6_5.0x5.0mm_P1.6mm
D19: LED; LED_1206_3216Metric_Pad1.42x1.75mm_HandSolder
J6: Conn_01x05_Socket; JST_PH_B5B-PH-K_1x05_P2.00mm_Vertical
R29, R30, R31, R32: 330; R_1206_3216Metric_Pad1.30x1.75mm_HandSolder

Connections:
+3V3: J6.2, R29.2
/LED_B: J6.5, R32.2
/LED_G: J6.4, R31.2
/LED_R: J6.3, R30.2
GND: D1.4 (GND), D1.5 (GND), D1.6 (GND), D19.1 (K), J6.1
unnamed: D1.1 (BLUE), R32.1
unnamed: D1.3 (GREEN), R31.1
unnamed: D1.2 (RED), R30.1
unnamed: D19.2 (A), R29.1

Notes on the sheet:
Indicate Unit
LED


Board: 2 copper layers, 38.5 x 30.0 mm, 7 parts (1 on the bottom side), 9 nets.

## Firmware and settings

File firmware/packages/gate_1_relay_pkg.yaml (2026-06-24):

substitutions:
  # Podstawowe
  entity_id: gate1
  device_id: extender_1
  
  # MCP - używamy ID z głównego pliku
  mcp_id: mcp_1                       # <-- zmienione z mcp_address na mcp_id
  
  # Piny na MCP23017
  relay_pin: 0
  button_pin: 1
  sensor_gate_closed_pin: 2
  sensor_gate_opened_pin: 3
  
  # Czas wyzwalania przekaźnika
  relay_trigger_time: 1s

# ============================================
# NIE DEFINIUJEMY MCP23017 TUTAJ - jest w głównym pliku
# ============================================

globals:
  - id: ${entity_id}_gate_position
    type: float
    restore_value: false
    initial_value: '0.0'

  - id: ${entity_id}_gate_state
    type: int
    restore_value: false
    initial_value: '0'
    # 0 - closed, 1 - opening, 2 - opened, 3 - closing

  - id: ${entity_id}_button_state
    type: int
    restore_value: false
    initial_value: '0'
    # 0 - stop, 1 - open, 2 - stop, 3 - close

  - id: ${entity_id}_is_tuned
    type: bool
    restore_value: false
    initial_value: 'false'

  - id: ${entity_id}_stop_gate_indicator
    type: bool
    restore_value: false
    initial_value: 'false'

# ============================================
# PRZYCISK FIZYCZNY
# ============================================
binary_sensor:
  - platform: gpio
    name: "${entity_id}_physical_button"
    id: ${entity_id}_button
    device_id: ${device_id}
    pin:
      mcp23xxx: ${mcp_id}
      number: ${button_pin}
      mode: INPUT
      inverted: true
    on_press:
        then:
          - script.execute: ${entity_id}_handle_button_press

  - platform: gpio
    name: "${entity_id}_gate_closed_sensor"
    id: ${entity_id}_gate_closed_sensor
    device_id: ${device_id}
    pin:
      mcp23xxx: ${mcp_id}
      number: ${sensor_gate_closed_pin}
      mode: INPUT
      inverted: true
    filters:
      - delayed_on: 100ms
      - delayed_off: 100ms

  - platform: gpio
    name: "${entity_id}_gate_opened_sensor"
    id: ${entity_id}_gate_opened_sensor
    device_id: ${device_id}
    pin:
      mcp23xxx: ${mcp_id}
      number: ${sensor_gate_opened_pin}
      mode: INPUT
      inverted: true
    filters:
      - delayed_on: 100ms
      - delayed_off: 100ms


# ============================================
# PRZYCISKI WIRTUALNE (do testów)
# ============================================
button:
  - platform: template
    name: "${entity_id}_virtual_click"
    id: ${entity_id}_virtual_click
    device_id: ${device_id}
    icon: "mdi:gesture-tap-button"
    on_press:
      - logger.log: "${entity_id}: Wirtualny klik"
      - script.execute: ${entity_id}_handle_button_press

# ============================================
# PRZEKAŹNIKI
# ============================================
switch:
  - platform: gpio
    name: "${entity_id}_relay"
    id: ${entity_id}_relay
    device_id: ${device_id}
    pin:
      mcp23xxx: ${mcp_id}              # <-- używamy mcp_id
      number: ${relay_pin}
      mode: OUTPUT
      inverted: true
    restore_mode: ALWAYS_OFF

  - platform: template
    name: "${entity_id}_virt_close_sensor"
    id: ${entity_id}_virt_close_sensor
    device_id: ${device_id}
    icon: "mdi:gate-closed"
    optimistic: true
    lambda: |-
      return id(${entity_id}_virt_close_sensor).state;
    on_turn_on:
      - script.execute: ${entity_id}_update_gate_closed
    on_turn_off:
      - logger.log: "${entity_id}: XXX"

  - platform: template
    name: "${entity_id}_virt_open_sensor"
    id: ${entity_id}_virt_open_sensor
    device_id: ${device_id}
    icon: "mdi:gate-open"
    optimistic: true
    lambda: |-
      return id(${entity_id}_virt_open_sensor).state;
    on_turn_on:
      - script.execute: ${entity_id}_update_gate_opened
    on_turn_off:
      - logger.log: "${entity_id}: XXX"
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

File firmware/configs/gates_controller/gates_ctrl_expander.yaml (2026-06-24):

substitutions:
  entity_id: gates_expander
  mcp_address: 0x20
  device_id: extender_1
  gate_name: "Brama Wjazdowa"
  relay_trigger_time: 1s

mcp23017:
  - id: garage_mcp
    address: ${mcp_address}



packages:
  # gates_controller: !include
  #   file: /my_components_firm/packages/gate_3_relays_pkg.yaml
  #   vars:
  #     entity_id: "entry_gate"
  #     device_id: ${device_id}
  #     mcp_id: garage_mcp                   # <-- używamy ID z głównego pliku
  #     relay_open_pin: 0
  #     relay_close_pin: 1
  #     relay_stop_pin: 2
  #     button_pin: 3
  #     relay_trigger_time: 1s
  # gates_controller_1: !include
  #   file: /my_components_firm/packages/gate_3_relays_pkg.yaml
  #   vars:
  #     entity_id: "garage_gate_1"
  #     device_id: ${device_id}
  #     mcp_id: garage_mcp                    # <-- używamy ID z głównego pliku
  #     relay_open_pin: 4
  #     relay_close_pin: 5
  #     relay_stop_pin: 6
  #     button_pin: 7
  #     relay_trigger_time: 1s
  gates_controller_2: !include
    file: /my_components_firm/packages/gate_1_relay_pkg.yaml
    vars:
      entity_id: "garage_gate_1"
      device_id: ${device_id}
      mcp_id: garage_mcp                    # <-- używamy ID z głównego pliku
      relay_pin: 4
      button_pin: 7
      relay_trigger_time: 1s





# globals:
#   - id: gate_stop_active
#     type: bool
#     restore_value: no
#     initial_value: 'false'

#   - id: gate_position
#     type: float
#     restore_value: true
#     initial_value: '0.0'  # 0 = zamknięta, 100 = otwarta
  
#   - id: button_state
#     type: int
#     restore_value: true
#     initial_value: '0'    # 0 = OPEN, 1 = STOP, 2 = CLOSE, 3 = STOP

# # ============================================
# # PRZYCISK FIZYCZNY (BINARY SENSOR)
# # ============================================
# binary_sensor:
#   - platform: gpio
#     name: "${entity_id}_physical_button"
#     id: ${entity_id}_button
#     device_id: ${device_id}
#     pin:
#       mcp23xxx: ${entity_id}_mcp
#       number: 3      # GPIO3 na MCP23017 - podłącz przycisk do masy
#       mode: INPUT
#       inverted: true
#     filters:
#       - delayed_on_off: 50ms  # Filtrowanie drgań styków
#     on_click:
#       - min_length: 50ms
#         max_length: 1000ms
#         then:
#           - logger.log: "Krótkie kliknięcie - przełączanie stanu"
#           - script.execute: ${entity_id}_handle_short_press
#     on_multi_click:
#     - timing:
#         - ON for at least 1000ms
#       then:
#         - logger.log: "Długie przytrzymanie - OPEN HOLD"
#         - globals.set:
#             id: button_state
#             value: '1'  # Reset do OPEN
#         - switch.turn_on: ${entity_id}_open_hold

# button:
#   - platform: template
#     name: "${entity_id}_virtual_click"
#     id: ${entity_id}_virtual_click
#     device_id: ${device_id}
#     icon: "mdi:gesture-tap-button"
#     on_press:
#       - logger.log: "WIRTUALNY: krótkie kliknięcie"
#       - script.execute: ${entity_id}_handle_short_press

#   - platform: template
#     name: "${entity_id}_virtual_hold"
#     id: ${entity_id}_virtual_hold
#     device_id: ${device_id}
#     icon: "mdi:gesture-tap-hold"
#     on_press:
#       - logger.log: "WIRTUALNY: długie przytrzymanie"
#       - globals.set:
#           id: button_state
#           value: '1'
#       - switch.turn_on: ${entity_id}_open_hold

# # ============================================
# # PRZEKAŹNIKI (FIZYCZNE) - używamy pinów z MCP23017
# # ============================================
# switch:
#   # Przekaźnik dla funkcji OPEN
#   - platform: gpio
#     name: "${entity_id}_relay_open"
#     id: ${entity_id}_relay_open
#     device_id: ${device_id}
#     pin:
#       mcp23xxx: ${entity_id}_mcp
#       number: 0      # GPIO0 na MCP23017
#       mode: OUTPUT
#       inverted: true
#     restore_mode: ALWAYS_OFF
    
#   # Przekaźnik dla funkcji CLOSE
#   - platform: gpio
#     name: "${entity_id}_relay_close"
#     id: ${entity_id}_relay_close
#     device_id: ${device_id}
#     pin:
#       mcp23xxx: ${entity_id}_mcp
#       number: 1      # GPIO1 na MCP23017
#       mode: OUTPUT
#       inverted: true
#     restore_mode: ALWAYS_OFF
    
#   # Przekaźnik dla funkcji STOP
#   - platform: gpio
#     name: "${entity_id}_relay_stop"
#     id: ${entity_id}_relay_stop
#     device_id: ${device_id}
#     pin:
#       mcp23xxx: ${entity_id}_mcp
#       number: 2      # GPIO2 na MCP23017
#       mode: OUTPUT
#       inverted: true
#     restore_mode: ALWAYS_OFF
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

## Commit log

2026-05-28 [ADD] first commit
    [controller_board.kicad_pcb, controller_board.kicad_sch, digital_inputs.kicad_sch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]
2026-05-28 [FIX] layout of template extention board
    [extension_module_template.kicad_pcb, extension_module_template.kicad_sch]
2026-05-31 [CHANGE] i2c adressing
    [main_board.kicad_sch]
2026-05-31 [ADD] two rows extention module
    [extension_module_two_rows_10cm_template.kicad_pcb, extension_module_two_rows_10cm_template.kicad_sch]
2026-05-31 [ADD] lauout for relay expander pcb
    [digital_inputs.kicad_sch, main_board.kicad_pcb, main_board.kicad_sch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]
2026-05-31 [ADD] ui board template
    [digital_inputs.kicad_sch, main_board.kicad_sch, relays.kicad_sch]
2026-05-31 [ADD] ui-board for relay - basic layout
    [main_board.kicad_pcb, main_board.kicad_sch, ui_board.kicad_pcb]
2026-06-01 [ADD] ui_board finished setup]
    [ui_board.kicad_pcb, ui_board.kicad_sch]
2026-06-01 [UPDATE] ui_board connector position
    [ui_board_template.kicad_pcb]
2026-06-01 [PDATE] ui module]
    [ui_board.kicad_pcb]
2026-06-01 [FIX] move connector on ui board
    [ui_board.kicad_pcb]
2026-06-01 [FIX] problem with connector to expander board
    [main_board.kicad_pcb, ui_board.kicad_pcb]
2026-06-01 [ADD] board connector
    [boards_connector.kicad_pcb, boards_connector.kicad_sch, boards_connector.step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]
2026-06-01 [FIX] placement of connector for UI panel
    [main_board.kicad_pcb]
2026-06-01 [ADD] generate step file for relay main controller
    [main_board.step]
2026-06-02 [ADD] routing on main pcb board
    [digital_inputs.kicad_sch, main_board.kicad_pcb, relays.kicad_sch]
2026-06-02 [FIX] add 12V trace for expanders and generate gerber for all relays related boards
    [boards_connector.kicad_pcb, digital_inputs.kicad_sch, main_board.kicad_pcb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]
2026-06-08 [ADD] data for pin in relay expander
2026-06-08 [FIX] add missing enable buttons for sprinkler extention board
2026-06-09 [ADD] relay_expander firmware
2026-06-24 [ADD] logic for one relay gate
2026-06-24 [ADD] current operation for one relay gate controller
